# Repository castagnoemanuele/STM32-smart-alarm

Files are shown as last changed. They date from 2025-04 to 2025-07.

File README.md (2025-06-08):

# STM32-Smart-Alarm

Smart alarm system based on STM32 as the main microcontroller, interfaced with ESP32 for WiFi communications.

## Introduction

This project is an advanced alarm system designed for home and office security. It combines PIN-based authentication, environmental monitoring, and remote notifications through:

- Authentication via keypad and PIN code  
- Detection of door/window openings and motion  
- Real-time WhatsApp notifications  
- User interface on OLED display

Demo Video on YouTube (https://www.youtube.com/watch?v=71LS64RbG-M)

## Hardware Components

- **STM32 Nucleo-64 Board**: Main processing unit 
- **ESP32 Wemos S2 mini Module**: WiFi handling and notifications  
- **128x64 I2C OLED Display**: User interface  
- **4x4 Matrix Keypad**: PIN code entry  
- **Reed Switch Sensor**: Door/window opening detection  
- **HC-SR501 PIR Sensor**: Motion detection  
- **Active Buzzer**: Acoustic siren  

## System Architecture

Block Diagram

The system is divided into two main units:

1. **STM32 Nucleo-64**:
   - Sensor and alarm logic management  
   - Display and user interface control  
   - I2C communication with ESP32  

2. **ESP32 Wemos S2 mini**:
   - WiFi connection and notifications  
   - Web interface configuration  
   - WhatsApp message dispatch  

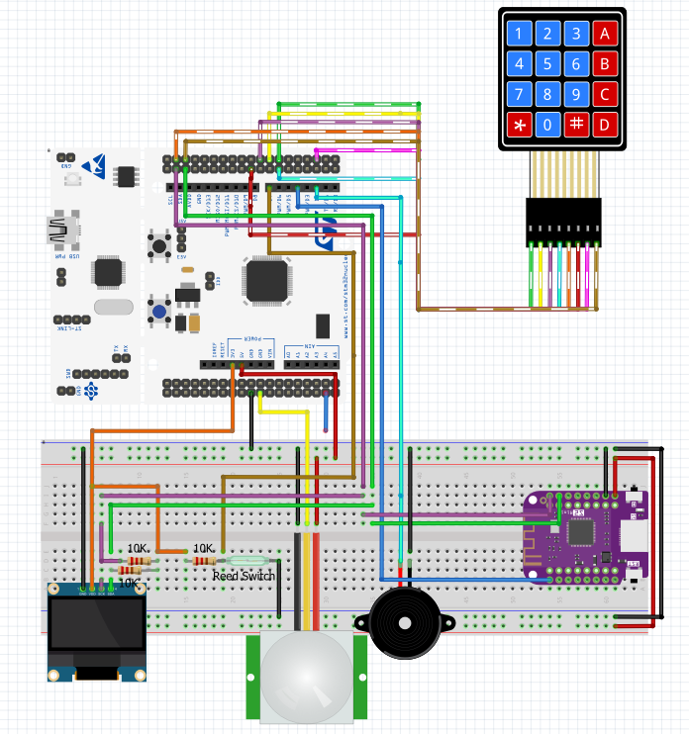
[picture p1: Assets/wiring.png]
Wiring Diagram


## Key Features

### 1. 4x4 Matrix Keypad

Used for PIN code input:

- 8 total pins (4 rows as output, 4 columns as input)  
- Integrated software debounce (500 ms)  
- Visual feedback during entry  

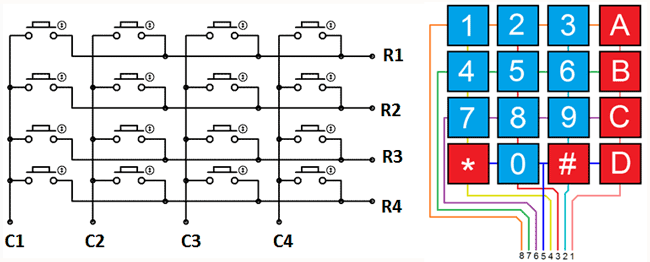
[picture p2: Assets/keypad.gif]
Keypad Functioning
  
*Credits: [Antonio Mancuso's Blog](https://mancusoa74.blogspot.com/2017/02/scratch-e-arduino-progetto-6-tastierino.html)*

```c
static const char keypad[4][4] = {
    {'1','2','3','A'},
    {'4','5','6','B'},
    {'7','8','9','C'},
    {'*','0','#','D'}
};
```

### 2. Alarm System

**Triggers**:

- Door/window openings (reed switch)  
- Unauthorized movements (PIR sensor)   

**Actions**:

- Activate buzzer  
- Immediate WhatsApp alert  
- OLED display blinking  

### 3. Security Management

- PIN code authentication  
- Temporary lockout after 3 failed attempts (configurable)  
- PIN code stored in flash memory   

## Firmware flowchart

Flowchart

## Project Status

### Hardware:

- [x] Schematic creation  
- [x] Full component testing  
- [x] Integrated shield development  

### STM32 Firmware:

- [x] Display initialization  
- [x] Flash-based PIN management  
- [x] Alarm functions  
- [x] Reed switch via interrupt  
- [x] PIR sensor integration  
- [x] I2C communication with ESP32  

### ESP32 Firmware:

- [x] WiFi connection  
- [x] IP information dispatch  
- [x] WhatsApp notifications  

## Installation

### Prerequisites

- STM32CubeIDE for STM32 development  
- Arduino IDE for ESP32 programming  
- Required libraries (see section below) 

## Libraries Used

This project makes use of the following open-source libraries:
- [STM32 SSD1306 library](https://github.com/afiskon/stm32-ssd1306): For interfacing with the OLED display.
- [WiFiManager](https://github.com/tzapu/WiFiManager): Simplifies WiFi connectivity setup.

### Steps
1. **Clone the Repository**:
   ```bash
   git clone https://github.com/castagnoemanuele/STM32-smart-alarm.git
   cd STM32-smart-alarm
   ```

2. **Hardware Setup**:
   - Connect all components as per the provided schematic.
   - Ensure proper power supply and secure connections.

3. **Flashing the STM32**:
   - Open the project in STM32CubeIDE.
   - Compile the source code and flash it to the STM32 Nucleo-64 board.

4. **Flashing the ESP32**:
   - Open the ESP32 code in Arduino IDE.
   - Compile and upload the code to the ESP32 S2 mini board.

5. **WhatsApp Notification Setup**:
   - To receive WhatsApp notifications when an alarm is triggered, you need to obtain an API key from CallMeBot:
     1. Add the phone number +34 694 29 84 96 to your phone contacts (name it as you wish)
     2. Send the message "I allow callmebot to send me messages" to this contact via WhatsApp
     3. Wait to receive the message "API Activated for your phone number. Your APIKEY is XXXXXX" from the bot
     4. Enter your phone number (with international prefix) and the received APIKEY in the WiFiManager configuration interface
   - Note: If you don't receive the API key within 2 minutes, please try again after 24 hours.
   
   Example of activation message exchange with CallMeBot:
   
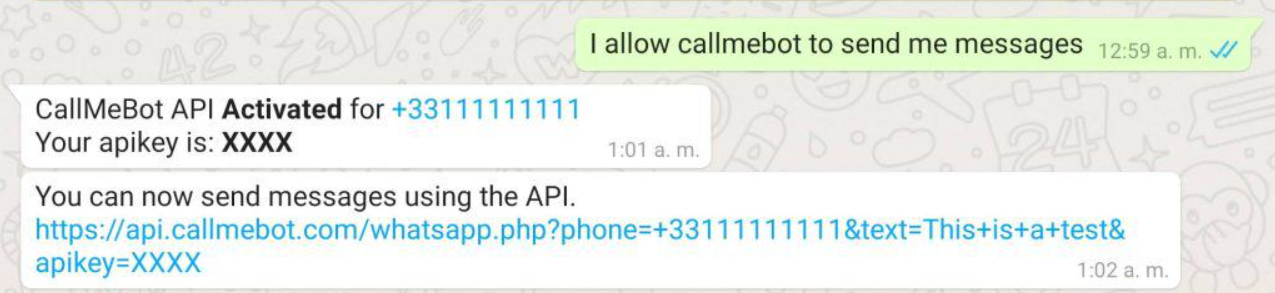
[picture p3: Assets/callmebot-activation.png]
CallMeBot Activation
   

6. **ESP32 Setup**:
   - On power-up, connect to the "AutoConnectAP" network  
   - Enter WiFi credentials in the web interface  
   - Set phone number and WhatsApp API key  

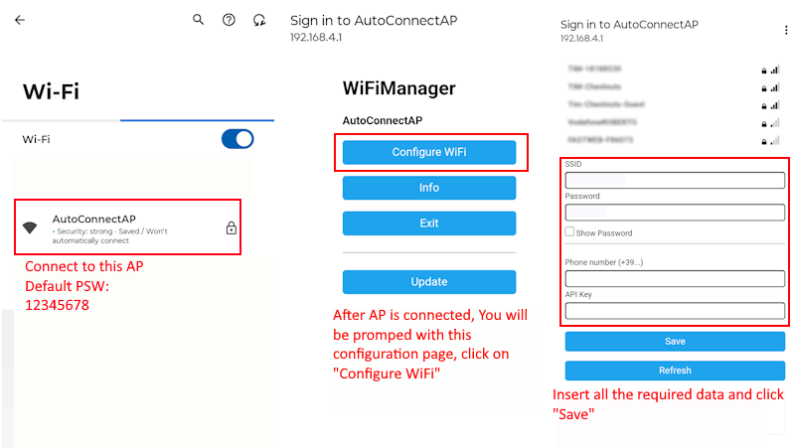
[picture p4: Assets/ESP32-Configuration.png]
ESP32 Configuration
   

## Usage

1. **Arming the system**:
   - Press 'A' and enter your PIN  
   - Confirm with 'D'  

2. **Disarming**:
   - Enter PIN when prompted

## Technical Notes

### Known Issues

- For ESP32, use `driver/i2c.h` instead of `Wire.h`  
- Power components with 5V for stability

## License

This project is licensed under the [MIT License](LICENSE).

## Acknowledgments

Special thanks to the authors of the open-source libraries and the community for their valuable contributions.

---

**Future Developments**:

- Mobile app for remote control  
- Home Assistant integration  
- GSM module for SMS alerts  
- Multi-zone expansion

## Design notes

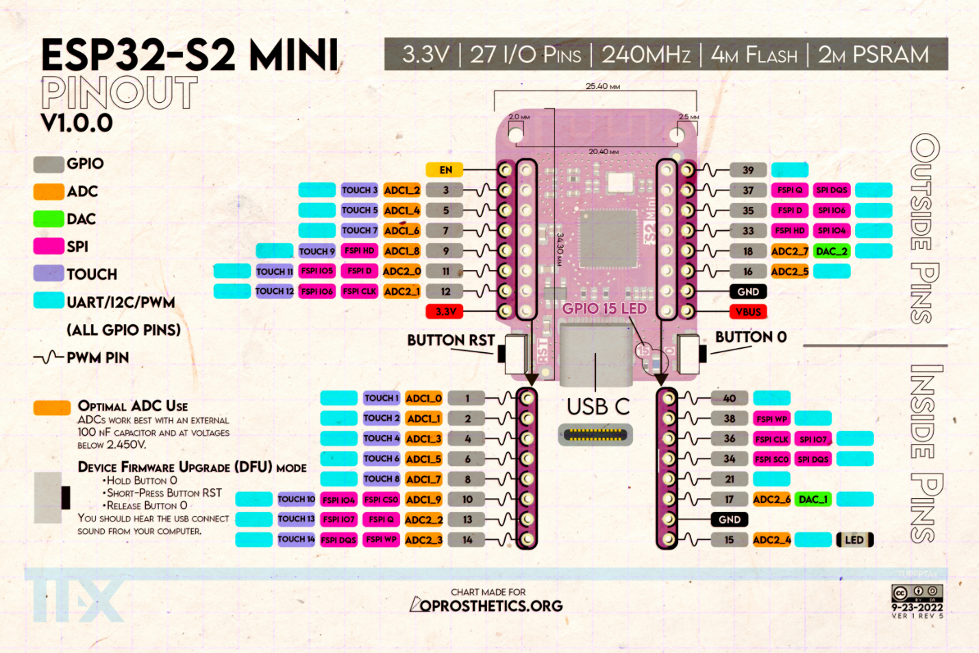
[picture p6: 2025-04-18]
Assets/ESP-32-s2-pinout.png

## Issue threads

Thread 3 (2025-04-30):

Communication with ESP32- ESP32 does not always connect to wifi succesfully

castagnoemanuele, 2025-04-30:
Possible Fix: implement a reset procedure in case connection fails and ask for ip again (maybe in the background)

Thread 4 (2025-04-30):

I2C Scan - ESP32 address not printed

castagnoemanuele, 2025-04-30:
Sometimes even when the ESP32 connects to WiFi and sends the IP correctly to the STM32, it's addres is not printed on the display. Not that relevant

castagnoemanuele, 2025-04-30:
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

Issue as pictured

castagnoemanuele, 2025-05-08:
Seems to be solved with soldering I2C lines - cannot replicate anymore

Closed 2025-05-08.

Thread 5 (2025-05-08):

I2C-SPI related - When ESP32 connects to wifi successfuly the RFID tag reads nothing

castagnoemanuele, 2025-05-08:
When ESP32 connects to wifi successfuly the RFID tag reads nothing, when the ESP32 is not present or does not find a network the RFID reader works

Possible reasons:

- blocking HAL function calls
- Too high power draw from esp

castagnoemanuele, 2025-05-14:
Many things tried:

- Polling SPI communication
- Adding capacitors on 3.3v
- large delay after ESP32 boot -  to isolate the possible power draw problem
- disabled DMA for ESP32

Might need to be tested:

- changing I2C1 and SPI3 to other buses

castagnoemanuele, 2025-05-20:
Turns out that the pin we used for the RST was also shared with JTAG, possibly what caused all our issues

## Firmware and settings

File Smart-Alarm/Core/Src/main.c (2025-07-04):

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
/* Includes ------------------------------------------------------------------*/
#include "main.h"

/* USER CODE BEGIN Includes */
#include "config.h"
#include "display.h"
#include "flashMemory.h"
#include "stdio.h"
#include "string.h"
#include "ctype.h"
#include "pinCode.h"
#include "esp32.h"
#include "keypad.h"
/* USER CODE END Includes */

I2C_HandleTypeDef hi2c1;
DMA_HandleTypeDef hdma_i2c1_rx;
DMA_HandleTypeDef hdma_i2c1_tx;

TIM_HandleTypeDef htim1;
TIM_HandleTypeDef htim2;
DMA_HandleTypeDef hdma_tim1_up;

UART_HandleTypeDef huart2;

/* USER CODE BEGIN PV */
volatile uint8_t alarm_flag = 0;
volatile uint8_t key_pressed = 0;
volatile uint8_t reed_triggered = 0;
char last_key = '\0';
uint32_t last_key_time = 0;
uint32_t last_reed_time = 0;
uint32_t start_time = 0;
bool toggle = false;
bool message_sent = false;

// Main loop timing variables
uint32_t loop_start_time = 0;

PincodeState pincodeState;

char rx_data[DATA_SIZE];

uint8_t value = 0;
char str1[17] = { '\0' };
char str2[17] = { '\0' };
char str3[17] = { '\0' };
char str4[17] = { '\0' };
char tmp_str[65] = { '\0' };

// Delay function:
#define	Precise_Delay(x) {\
	uint32_t x1 = x * 72;\
	DWT->CYCCNT = 0;\
	while (DWT->CYCCNT < x1);\
}

/* USER CODE END PV */

void SystemClock_Config(void);
static void MX_GPIO_Init(void);
static void MX_DMA_Init(void);
static void MX_USART2_UART_Init(void);
static void MX_I2C1_Init(void);
static void MX_TIM2_Init(void);
static void MX_TIM1_Init(void);
/* USER CODE BEGIN PFP */
int ScanI2CDevices(void);
void TriggerAlarm(void);
void StopAlarm(void);
void HandleReedSwitch(void);
void HandlePIRMotion(void);

/* USER CODE END PFP */

/* USER CODE BEGIN 0 */
int __io_putchar(int ch) {
	HAL_UART_Transmit(&huart2, (uint8_t*) &ch, 1, HAL_MAX_DELAY);
	return ch;
}
int fputc(int ch, FILE *f) {
	return __io_putchar(ch);
}

/* USER CODE END 0 */

/**
 * @brief  The application entry point.
 * @retval int
 */
int main(void) {

	/* USER CODE BEGIN 1 */
	uint8_t data[] = { 0xFF, 0x0 };
	/* USER CODE END 1 */

	/* MCU Configuration--------------------------------------------------------*/

	/* Reset of all peripherals, Initializes the Flash interface and the Systick. */
	HAL_Init();

	/* Configure the system clock */
	SystemClock_Config();

	/* Initialize all configured peripherals */
	MX_GPIO_Init();
	MX_DMA_Init();
	MX_USART2_UART_Init();
	MX_I2C1_Init();
	MX_TIM2_Init();
	MX_TIM1_Init();
	/* USER CODE BEGIN 2 */
	setvbuf(stdout, NULL, _IONBF, 0); //disable waiting for newline
	printf("Booting STM32...\r\n");
	Display_Init();
	Display_BootMessage();
	printf("Display initialized...\r\n");
	Pincode_Init(&pincodeState);

	// Enable ESP32
	HAL_GPIO_WritePin(ESP32_EN_Port, ESP32_EN, GPIO_PIN_SET);
	HAL_Delay(8000); // Give more time to the ESP to boot and initialize I2C completely

	// Read saved pincode from flash
	uint32_t saved_pincode = ReadFromFlash(address1);
	char pincode_str[12];
	sprintf(pincode_str, "%lu", (unsigned long) saved_pincode);

	// Scan I2C devices
	ScanI2CDevices();
	HAL_Delay(1000);

	// Get IP from ESP32
	printf("\nRequesting IP address to ESP32");
	esp32getIP();

	HAL_Delay(1000);
	// Show system status
	Display_SystemStatus(pincodeState.system_armed);
	char pressed_key = '\0';
	if (wifi_connected) {
		HAL_TIM_Base_Start(&htim1);
		HAL_DMA_Start(&hdma_tim1_up, (uint32_t) data, (uint32_t) &GPIOA->ODR,
				5);
		__HAL_TIM_ENABLE_DMA(&htim1, TIM_DMA_UPDATE);
	}

	/* USER CODE END 2 */

	/* Infinite loop */
	/* USER CODE BEGIN WHILE */
	/* Main loop */
	while (1) {
		// Record start time for main loop timing control
		loop_start_time = HAL_GetTick();

		// Check if system is locked
		if (pincodeState.system_locked) {
			uint32_t remaining = (LOCKOUT_TIME_MS
					- (HAL_GetTick() - pincodeState.lockout_start)) / 1000;
			Display_LockedScreen(remaining);

			if ((HAL_GetTick() - pincodeState.lockout_start) >= LOCKOUT_TIME_MS) {
				pincodeState.system_locked = false;
				pincodeState.pin_attempts = 0;
				Display_SystemStatus(pincodeState.system_armed);
			}
			HAL_Delay(100);
			continue;
		}

		// Scan keypad
		pressed_key = scan_keypad();
		if (pressed_key != '\0') {
			handle_keypress(pressed_key);
		}

		// Check reed switch status
		HandleReedSwitch();

		// Handle alarm
		if (alarm_flag) {
			if (start_time == 0) {
				start_time = HAL_GetTick();
				printf("Alarm start: start_time = %lu\r\n", start_time);
			}

			// Keep buzzer active during alarm (toggle every 100ms)
			HAL_GPIO_TogglePin(GPIOA, BUZZER_PIN);

			// If we are not entering the PIN, continue with the flashing display
			if (!pincodeState.entering_pin_during_alarm) {
				Display_AlarmScreen(toggle);
				toggle = !toggle;
			}

			HAL_Delay(100);
		} else {
			// If the alarm has been stopped, make sure the buzzer is off
			HAL_GPIO_WritePin(GPIOA, BUZZER_PIN, GPIO_PIN_RESET);
		}

		// Handle PIR
		HandlePIRMotion();
		
		// Main loop timing control - ensure 250ms cycle time
		uint32_t loop_execution_time = HAL_GetTick() - loop_start_time;
		
		// Print timing information for debugging
		printf("Loop execution time: %lu ms, Target: %lu ms\r\n", 
			   loop_execution_time, MAIN_LOOP_PERIOD_MS);
		
		if (loop_execution_time > MAIN_LOOP_PERIOD_MS) {
			printf("WARNING: Loop execution time (%lu ms) exceeded target period (%lu ms)!\r\n", 
				   loop_execution_time, MAIN_LOOP_PERIOD_MS);
		} else {
			uint32_t delay_time = MAIN_LOOP_PERIOD_MS - loop_execution_time;
			printf("Adding delay: %lu ms to reach 250ms target\r\n", delay_time);
			HAL_Delay(delay_time);
		}
		
		// Print total loop time after delay
		uint32_t total_loop_time = HAL_GetTick() - loop_start_time;
		printf("Total loop time: %lu ms\r\n\r\n", total_loop_time);
	}

	/* USER CODE END WHILE */

}

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
/* USER CODE BEGIN 4 */

//Old testing interrupt
void EXTI15_10_IRQHandler(void) {
	if (__HAL_GPIO_EXTI_GET_IT(BUTTON_PIN) != RESET) {
		__HAL_GPIO_EXTI_CLEAR_IT(BUTTON_PIN);
		if (pincodeState.system_armed) {
			TriggerAlarm();
		}
	}
}

void EXTI9_5_IRQHandler(void) {
	if (__HAL_GPIO_EXTI_GET_IT(REED_SWITCH_PIN) != RESET) {
		if ((HAL_GetTick() - last_reed_time) > REED_DEBOUNCE_MS) {
			last_reed_time = HAL_GetTick();
			__HAL_GPIO_EXTI_CLEAR_IT(REED_SWITCH_PIN);
			reed_triggered = 1;
		}
	}
}

void HandleReedSwitch(void) {
	if (reed_triggered && pincodeState.system_armed) {
		reed_triggered = 0;
		// Send message to ESP32
		if (!pincodeState.message_sent) {
			pincodeState.message_sent = true;  // Imposta a true dopo l'invio
			uint8_t send_byte = '3'; // Command to signal open door/window
			HAL_StatusTypeDef tx_status = HAL_I2C_Master_Transmit(&hi2c1,
					(I2C_ADDR << 1), &send_byte, 1, HAL_MAX_DELAY);
		}
		TriggerAlarm();
	}
}

void TriggerAlarm(void) {
	if (!alarm_flag) {
		alarm_flag = 1;
		HAL_GPIO_WritePin(GPIOA, BUZZER_PIN, GPIO_PIN_SET);
		printf("Allarme attivato: alarm_flag = %d\r\n", alarm_flag);
	}
}

void StopAlarm(void) {
	alarm_flag = 0;
	HAL_GPIO_WritePin(GPIOA, BUZZER_PIN, GPIO_PIN_RESET);
	printf("Allarme fermato: alarm_flag = %d, buzzer spento\r\n", alarm_flag);

	// Resettare start_time a zero per futuri allarmi
	extern uint32_t start_time;
	start_time = 0;

	// Assicurarsi che il buzzer sia effettivamente spento
	HAL_GPIO_WritePin(GPIOA, BUZZER_PIN, GPIO_PIN_RESET);

	// Pulire lo schermo ma non aggiornare lo stato perché verrà fatto da Pincode_Check
	ssd1306_Fill(Black);
	ssd1306_UpdateScreen();
}

int ScanI2CDevices(void) {
	const char StartMSG[] = "Starting I2C scan...\r\n";
	const char EndMSG[] = "I2C scan complete.\r\n";
	const uint8_t Space[] = " ";
	char Buffer[32];

	uint8_t i, ret;
	char buffer[16];
	int found = 0;

	ssd1306_Fill(Black);
	ssd1306_SetCursor(0, 0);
	ssd1306_WriteString("I2C Scan:", Font_7x10, White);
	ssd1306_UpdateScreen();

	HAL_Delay(500);

	printf("%s", StartMSG);

	for (i = 1; i < 128; i++) {
		ret = HAL_I2C_IsDeviceReady(&hi2c1, (uint16_t) (i << 1), 3, 5);
		if (ret == HAL_OK) {
			sprintf(Buffer, "0x%X", i);
			HAL_UART_Transmit(&huart2, Buffer, sizeof(Buffer), 10000);

			sprintf(buffer, "Found: 0x%02X", i);
			ssd1306_SetCursor(0, 16 + found * 10);
			ssd1306_WriteString(buffer, Font_6x8, White);
			ssd1306_UpdateScreen();

			HAL_Delay(300);
			found++;
			if (found > 4)
				break;
		} else {
			HAL_UART_Transmit(&huart2, Space, sizeof(Space), 10000);
		}
	}

	HAL_UART_Transmit(&huart2, EndMSG, sizeof(EndMSG), 10000);
	return found;
}

void HandlePIRMotion(void) {
	static uint32_t last_pir_time = 0;
	static uint8_t pir_triggered = 0;

	// Read the current status of the PIR sensor
	uint8_t current_pir_state = HAL_GPIO_ReadPin(PIR_PORT, PIR_PIN);

	// If the sensor is active and the system is armed
	if (current_pir_state == GPIO_PIN_SET && pincodeState.system_armed) {
		// PIR Sensor Debounce
		if ((HAL_GetTick() - last_pir_time) > REED_DEBOUNCE_MS) {
			pir_triggered = 1;
			last_pir_time = HAL_GetTick();
			printf("Movement detected! Alarm activated.\r\n");
		}
	}

	// If motion was detected
	if (pir_triggered) {
		// If the message has not been sent yet
		if (!pincodeState.message_sent) {
			pincodeState.message_sent = true;  // Set to true after submit
			uint8_t send_byte = '2'; // Command to signal movement
			HAL_StatusTypeDef tx_status = HAL_I2C_Master_Transmit(&hi2c1,
					(I2C_ADDR << 1), &send_byte, 1, HAL_MAX_DELAY);
		}

		// Trigger the alarm
		TriggerAlarm();
		pir_triggered = 0;
	}
}

void HAL_TIM_PWM_PulseFinishedCallback(TIM_HandleTypeDef *htim) {
	if (htim->Instance == TIM2) {
		printf("DMA transfer completed for TIM2_CH1.\n");
	}
}

/* USER CODE END 4 */
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


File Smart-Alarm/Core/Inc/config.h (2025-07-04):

#ifndef CONFIG_H
#define CONFIG_H

/* System Configuration */
#define PINCODE_LENGTH 4
#define MAX_PIN_ATTEMPTS 3
#define LOCKOUT_TIME_MS 30000
#define KEY_DEBOUNCE_MS 500
#define REED_DEBOUNCE_MS 200
#define MAIN_LOOP_PERIOD_MS 250

//ESP32 Communication related
#define MAX_CONNECTION_ATTEMPTS 3
#define DATA_SIZE 20
#define I2C_ADDR 0x5C
#define ESP32_EN GPIO_PIN_5	// Reset
#define ESP32_EN_Port GPIOB

/* Pin Definitions */
#define REED_SWITCH_PIN    GPIO_PIN_8
#define BUZZER_PIN         GPIO_PIN_10
#define BUTTON_PIN         GPIO_PIN_13

// Integrated LED
#define LD2_Pin GPIO_PIN_5
#define LD2_GPIO_Port GPIOA

// ============================================
/*RC522 RFID Module Pin Configuration
 ============================================
 | RC522 Pin     | STM32 Pin     | Description             |
 |---------------|---------------|-------------------------|
 | VCC           | 3.3V          | Power supply (3.3V)     |
 | GND           | GND           | Ground                  |
 | RST           | PC2           | Reset pin               |
 | SDA/CS        | PD2           | Chip Select (SPI CS)    |
 | MOSI          | PC12          | Master Out Slave In     |
 | MISO          | PC11          | Master In Slave Out     |
 | SCK           | PC10          | SPI Clock               |*/
#define RC522_Rst_Pin GPIO_PIN_2
#define RC522_Rst_GPIO_Port GPIOC
#define RC522_CS_Pin GPIO_PIN_2
#define RC522_CS_GPIO_Port GPIOD

// PIR Sensor
#define PIR_PIN GPIO_PIN_7
#define PIR_PORT GPIOB

// Keypad Rows (PB15, PB1, PB2, PB10)
#define ROW1_PIN   GPIO_PIN_15
#define ROW2_PIN   GPIO_PIN_1
#define ROW3_PIN   GPIO_PIN_2
#define ROW4_PIN   GPIO_PIN_10
#define ROW_PORT   GPIOB

// Keypad Columns (PC6, PC7, PC4, PC5)
#define COL1_PIN   GPIO_PIN_6
#define COL2_PIN   GPIO_PIN_7
#define COL3_PIN   GPIO_PIN_4
#define COL4_PIN   GPIO_PIN_5
#define COL_PORT   GPIOC

// Keypad matrix definition
static const char keypad[4][4] = {
		{ '1', '2', '3', 'A' },
		{ '4', '5', '6', 'B' },
		{ '7', '8', '9', 'C' },
		{ '*', '0', '#', 'D' }
};

#endif /* CONFIG_H */

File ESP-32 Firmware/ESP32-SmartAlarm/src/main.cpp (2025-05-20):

#include <WiFiManager.h> // https://github.com/tzapu/WiFiManager
#include <Preferences.h>
#include <HTTPClient.h>
#include <Arduino.h>
#include <driver/i2c.h>

Preferences prefs;

String phoneNumber = "";
String apiKey = "";

#define SDA_PIN 37
#define SCL_PIN 39
#define I2C_ADDRESS 0x5C // I2C address of the slave device

void sendWhatsAppAlert(String message)
{
    // Check if phone number and API key are valid
    String phone = phoneNumber;
    String api = apiKey;
    phone.trim();
    api.trim();

    if (phone.length() == 0 || api.length() == 0)
    {
        Serial.println("[ERROR] Phone number or API key not set!");
        return;
    }

    String encodedMessage = "";
    for (int i = 0; i < message.length(); i++)
    {
        char c = message[i];
        if (isalnum(c))
        {
            encodedMessage += c;
        }
        else
        {
            encodedMessage += "%" + String(c, HEX);
        }
    }

    String url = "https://api.callmebot.com/whatsapp.php?phone=" + phone +
                 "&text=" + encodedMessage +
                 "&apikey=" + api;

    Serial.println("URL: " + url); // Print URL for debugging

    HTTPClient http; // Declare HTTPClient object

    http.begin(url);                                  // Initialize HTTP request
    http.addHeader("User-Agent", "ESP32-SmartAlarm"); // Add user-agent header
    int httpCode = http.GET();                        // Send GET request

    if (httpCode > 0)
    {
        Serial.println("[OK] WhatsApp sent! Response: " + String(httpCode));
    }
    else
    {
        Serial.println("[FAIL] Error sending WhatsApp: " + http.errorToString(httpCode));
    }

    http.end(); // End HTTP request
}

void setup()
{
    ///////////////////// SERIAL ///////////////////////
    Serial.begin(115200);
    delay(1000); // Give time for serial monitor to open

    /////////////////////// I2C ///////////////////////
    i2c_config_t conf = {};
    conf.sda_io_num = (gpio_num_t)SDA_PIN;
    conf.scl_io_num = (gpio_num_t)SCL_PIN;
    conf.sda_pullup_en = GPIO_PULLUP_ENABLE;
    conf.scl_pullup_en = GPIO_PULLUP_ENABLE;
    conf.mode = I2C_MODE_SLAVE;
    conf.slave.addr_10bit_en = 0;
    conf.slave.slave_addr = I2C_ADDRESS;

    Serial.println("[OK] I2C Slave started");    i2c_param_config(I2C_NUM_0, &conf);
    ESP_ERROR_CHECK(i2c_driver_install(I2C_NUM_0, I2C_MODE_SLAVE, 128, 128, 0));
    Serial.println("[OK] I2C Slave driver installed");

    /////////////////////// PINS ///////////////////////
    pinMode(LED_BUILTIN, OUTPUT); // Initialize LED digital pin 15 as an output

    // Flash LED to indicate boot
    digitalWrite(LED_BUILTIN, HIGH);
    delay(500);
    digitalWrite(LED_BUILTIN, LOW);
    delay(500);
    digitalWrite(LED_BUILTIN, HIGH);
    delay(500);
    digitalWrite(LED_BUILTIN, LOW);

    ////////////////////// WIFI ///////////////////////
    WiFiManager wm;

    WiFiManagerParameter custom_phone("phone", "Phone number (+39...)", "", 16);
    WiFiManagerParameter custom_api("apikey", "API Key", "", 40);

    wm.addParameter(&custom_phone);
    wm.addParameter(&custom_api);

    if (!wm.autoConnect("AutoConnectAP", "password"))
    {
        Serial.println("[FAIL] WiFi Connect failed, restarting");
        ESP.restart();
    }

    Serial.println("[OK] Connected to WiFi");
    digitalWrite(LED_BUILTIN, HIGH);

    prefs.begin("config", false);

    // If first time, save; else load existing
    if (String(custom_phone.getValue()).length() > 0 && String(custom_api.getValue()).length() > 0)
    {
        prefs.putString("phone", custom_phone.getValue());
        prefs.putString("apikey", custom_api.getValue());
        Serial.println("[OK] Saved new phone and API key");
    }

    // Load saved values into global vars
    phoneNumber = prefs.getString("phone", "");
    apiKey = prefs.getString("apikey", "");

    Serial.println("[INFO] Loaded phone: " + phoneNumber);
    Serial.println("[INFO] Loaded API key: " + apiKey);

    sendWhatsAppAlert("System ready and online"); // Test message

    prefs.end();
}

void loop()
{
    static uint8_t data[128];
    static size_t data_len = 0;
    static unsigned long lastBlink = 0;

    // Handle incoming data
    data_len = i2c_slave_read_buffer(I2C_NUM_0, data, sizeof(data), 10 / portTICK_PERIOD_MS);
    if (data_len > 0)
    {
        Serial.print("Received ");
        Serial.print(data_len);
        Serial.println(" byte(s):");

        for (size_t i = 0; i < data_len; i++)
        {
            Serial.print("Received char: ");
            Serial.println((char)data[i]);

            // Flash LED as feedback
            digitalWrite(LED_BUILTIN, LOW);
            delay(100);
            digitalWrite(LED_BUILTIN, HIGH);
            delay(100);

            if (data[i] == '1')
            {                // Send IP address to master
                String ipAddress = WiFi.localIP().toString();
                Serial.println("Sending IP: " + ipAddress);
                
                // Clear the buffer first
                memset(data, 0, sizeof(data));
                
                size_t ip_len = ipAddress.length();
                for (size_t j = 0; j < ip_len; j++)
                {
                    data[j] = ipAddress[j];
                }
                data[ip_len] = '\0'; // Ensure proper null termination
                
                // Use a timeout of 100ms instead of 10ms
                esp_err_t write_status = i2c_slave_write_buffer(I2C_NUM_0, data, ip_len + 1, 100 / portTICK_PERIOD_MS);
                
                if (write_status == ESP_OK) {
                    Serial.println("IP address sent successfully");
                } else {
                    Serial.println("Failed to send IP address: " + String(write_status));
                }

                Serial.println("Command 1 received: Sent IP address: " + ipAddress);
            }
            else if (data[i] == '2')
            {
                // Send WhatsApp alert for alarm
                Serial.println("Command 2 received: Sending alarm message via WhatsApp.");
                sendWhatsAppAlert("ALERT: Movement detected!");
            }
            else if (data[i] == '3')
            {
                // Send WhatsApp for door/window open
                Serial.println("Command 3 received: Sending door/window open message via WhatsApp.");
                sendWhatsAppAlert("ALERT: Door/Window opened!");
            }
            else
            {
                Serial.println("Unknown command received.");
            }
            data[i] = 0; // Clear data buffer for next read
        }
    }

    // Blink LED every 100ms (0.05s on, 0.05s off)
    if (millis() - lastBlink > 100)
    {
        digitalWrite(LED_BUILTIN, !digitalRead(LED_BUILTIN)); // Toggle LED state
        lastBlink = millis();
    }
}

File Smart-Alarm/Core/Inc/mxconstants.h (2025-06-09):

/**
 ******************************************************************************
 * File Name          : mxconstants.h
 * Description        : This file contains the common defines of the application
 ******************************************************************************
 *
 * COPYRIGHT(c) 2017 STMicroelectronics
 *
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
 ******************************************************************************
 */
/* Define to prevent recursive inclusion -------------------------------------*/
#ifndef __MXCONSTANT_H
#define __MXCONSTANT_H
/* Includes ------------------------------------------------------------------*/


#define B1_Pin GPIO_PIN_13
#define B1_GPIO_Port GPIOC
#define USART_TX_Pin GPIO_PIN_2
#define USART_TX_GPIO_Port GPIOA
#define USART_RX_Pin GPIO_PIN_3
#define USART_RX_GPIO_Port GPIOA
#define LD2_Pin GPIO_PIN_5
#define LD2_GPIO_Port GPIOA
#define TMS_Pin GPIO_PIN_13
#define TMS_GPIO_Port GPIOA
#define TCK_Pin GPIO_PIN_14
#define TCK_GPIO_Port GPIOA
#define SWO_Pin GPIO_PIN_3
#define SWO_GPIO_Port GPIOB
/**
 * @}
 */

/**
 * @}
 */

#endif /* __MXCONSTANT_H */
/************************ (C) COPYRIGHT STMicroelectronics *****END OF FILE****/

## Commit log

2025-04-12 interrupt for buzzer
2025-04-15 Added ESP32 project base code
2025-04-18 Added I2c connection to ESP32 and pinouts
2025-04-22 minor improvements but i2c still not working with esp32
    [main.c, main.cpp]
2025-04-23 first working i2c communication with ESP32 (changed library) and i2c scanner added to STM 32
    [Smart Alarm.fzz]
2025-04-23 improved IP request via I2C to the ESP32
    [Smart Alarm.fzz]
2025-04-23 added support to reset ESP32 via software at boot
    [Smart-Alarm.ioc, main.c]
2025-04-23 updated documentation
    [Smart Alarm.fzz]
2025-04-23 first implementation of keypad 4x4, some row not work
    [Smart-Alarm.ioc, main.c]
2025-04-27 reed switch implementation
2025-04-29 improve code modularity and other fixes
    [config.h, display.c, main.c]
2025-04-29 Updated mostly documentation
    [Smart Alarm.fzz]
2025-04-29 probably fixed truncated IP issue #1
    [config.h, display.c, main.c]
2025-04-30 Fixed code blocks problem
    [Smart-Alarm.ioc, main.c]
2025-05-03 Added first modifications to implement DMA blinking
2025-05-03 added dma led blinking
2025-05-03 adjusted two led with the same frequency
2025-05-03 flowchart added
2025-05-03 added library for SPI and RFID implementation
2025-05-04 added first test imlementation of the RFID scanner
    [Smart Alarm.fzz]
2025-05-10 Added first Whatsapp notifications from ESP32
2025-05-10 Rename ESP32 Configuration.png to ESP32-Configuration.png
2025-05-10 Moved ESP32 relative functions from main to the appropriate files
2025-05-11 Changed wiring and added PIR test
    [Smart Alarm.fzz]
2025-05-11 Implementation of PIR alert with WhatsApp messages, and fixed keypad problem
    [Smart-Alarm.ioc, esp32.c, main.c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]
2025-05-11 added flowchart.drawio
2025-05-11 Rename Untitled Diagram.drawio to flowchart.drawio
2025-05-13 corrected wiring
    [Smart Alarm.fzz]
2025-05-14 Fixed WhatsApp messages and added more comments
    [main.c]
2025-05-14 Fixed anothers WhatsApp bugs
    [main.c]
2025-05-20 possibly fixed issue #5, now RFID works also after esp32 connection
    [Smart-Alarm.ioc, config.h, esp32.c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]
2025-05-20 Update frizzing schematic
    [Smart Alarm.fzz]
2025-05-20 Updated the wiring diagram of the possible cause of issue #5
2025-06-08 Aggiorna flowchart.drawio
2025-06-08 flowchart.drawio.svg aggiunto

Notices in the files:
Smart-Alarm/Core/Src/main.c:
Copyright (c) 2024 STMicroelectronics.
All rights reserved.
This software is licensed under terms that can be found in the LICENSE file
